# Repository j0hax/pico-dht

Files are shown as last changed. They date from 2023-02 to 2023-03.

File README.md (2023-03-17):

# pico-dht
Digital temperature and humidity reporting for the Raspberry Pi Pico, used to continuously monitor a server room at the Mechanical Engineering Campus of Leibniz University Hannover.

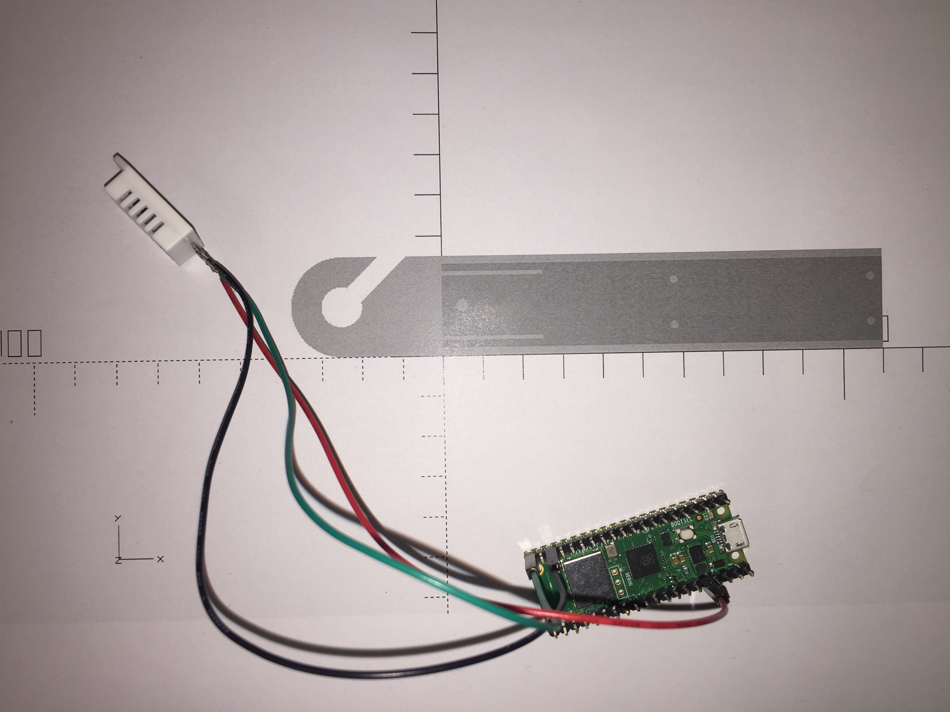
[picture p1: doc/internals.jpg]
The project without its case


## Hardware Used
1. Raspberry Pi Pico
2. DHT22/AM2302 or DHT11 sensor
3. Wires/Breadboard
4. 3D-printed case (optional)

### Wiring
| Pi Pico Label | Purpose | DHT22 Pin |
|---|---|---|
| 3V3 | Power | 1 |
| GPIO 15 | Data | 2 |
| GND | Ground  | 4 |

### Notes
- Many variants of the DHT22/DHT11 will have four pins. The third pin is unused.
- A pull-up resistor can be used but is not required, as the DHT22 has its own built-in.

## Install
By copying `main.py` to the Pico's on-board flash memory, it is executed at every boot.

Standard DHT drivers were [migrated](https://github.com/micropython/micropython/pull/9220) to `micropython-lib` starting with MicroPython 1.19, so most tutorials on the internet regarding this sensor no longer work!

The [dht](https://github.com/micropython/micropython-lib/blob/master/micropython/drivers/sensor/dht/dht.py) package can be copied over serial or installed OTA by modifying and executing `setup.py` on an internet-connected Pi Pico W. The library is should be saved to internal flash at `/lib`.

## Usage
A periodic timer is set to request sensor data every 3 seconds. The values are JSON encoded and printed over serial.[^1] The onboard LED will be on for the duration of this subroutine.

On most Linux hosts, the Pi Pico will be available under `/dev/ttyACM0`. The reading processes may need to part of the `dialout` group.

For an example implementation to read this data, see [dht22-nagios](https://github.com/j0hax/dht22-nagios).

### Connection Errors
If the wires are not soldered and knocked around, a connection may become flaky and a GPIO error can occur. Any errors when reading data are reported in the JSON's `error` attribute as a POSIX errno.

## Case
The 3D-Printed case can be used to mount the internals. It features a hook to hang the arrangement from the ceiling.

[OpenSCAD](https://openscad.org/) is used to model, customize and compile the final STL.

[^1]: Unfortunately, WPA2-EAP Networks such as eduroam are not supported very well by MicroPython at the moment.

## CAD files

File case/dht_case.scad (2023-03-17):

$fn=128;

// Sensor dimensions
/*
    swidth = 15 + 1;
    sheight = 25 + 1;
*/

swidth = 12 + 1;
sheight = 15.5 + 1;
sdepth = 5.5 + 1;

// Pi dimensions
pwidth = 21 + 2;
pheight = 51 + 2;

module hook(d=15, w=30, h=32) {
    difference() {
        hull() {
            //translate([0, 0, 10])
            cylinder(h=h/2, d=w);
            translate([w/2 - 1, -w/2, 0])
            cube([1, w, h]);
        }
        
        // Inner cylinder and slit
        cylinder(h=h, d=d);
        
        rotate([0, 0, 67.5])
        translate([0, -2.55, 0])
        cube([w, d/2, 30]);
    }
}

module sensorbody(l=100, w=30, h=30) {
    // Sensor offsets
    sxo = 2;
    syo = (w-swidth)/2;
    szo = h - sdepth;
    
    pxo = (l-pheight) - 2;
    pyo = (w-pwidth)/2;

    
    difference() {
        // Body
        cube([l, w, h]);
        
        // Sensor section
        translate([sxo, syo, szo])
        cube([sheight, swidth, sdepth]);
        
        // Cable channel
        mid = (w - 10) / 2;
        translate([sxo + sheight, mid, 2])
        cube([l, 10, h]);
        
        // Screw holes
        translate([l/3, 0, 0]) {
            translate([0, 5, 0])
            cylinder(h=h, d=3);
            
            
            translate([0, w-5, 0])
            cylinder(h=h, d=3);
        }
        
        // Pi section
        translate([pxo, pyo, 2])
        cube([pheight, pwidth, h]);
        
        // IKM Logo in the Pi Part
        translate([pheight, w, h/4])
        rotate([90, 0, 0])
        linear_extrude(w)
        import("ikm-logo.svg");
    }
    
    // Pin -- not needed for DHT11
    /*
        translate([sxo + (5.1 / 1.5), syo + swidth/2, szo])
        cylinder(d=2.9, h=(h-szo)/2);
    */
}

translate([-15, 15, 0])
hook();
sensorbody();

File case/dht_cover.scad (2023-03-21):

$fn=128;

// Sensor dimensions
swidth = 12 * 0.9;
sheight = 15.5 * 0.9;

// Pi dimensions
pwidth = 21 + 2;
pheight = 51 + 2;

module cover(l=100, w=30, h=2) {
    difference() {
        cube([l, w, h]);
        
        // Sensor Hole
        syo = (w-swidth)/2;
        sxo = 2;
        translate([sxo, syo, 0])
        cube([sheight, swidth, h]);
        
        // Screw Holes
        translate([l/3, 0, 0]) {
            translate([0, 5, 0])
            cylinder(h=h, d=3);
            
            
            translate([0, w-5, 0])
            cylinder(h=h, d=3);
        }
    }
    
    // Bottom cover
    hull() {
       inswidth = 9;
       byo = (w - inswidth) / 2;
       translate([l - 2, byo, -22]) {
           translate([-10, 0, 22])
           cube([1, inswidth, 1]);
           cube([2, inswidth, 22]);
       }
    }
}

cover();

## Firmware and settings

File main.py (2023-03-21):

import json
import errno
import _thread
from utime import sleep
from lib.dht import DHT11
from machine import Pin, ADC

sleep(1)

# Address the onboard LED
led = Pin("LED", Pin.OUT)

# Address the DHT22 Module
sensor = DHT11(Pin(15, Pin.IN, Pin.PULL_UP))

# Address the onboard temperature diode
sensor_diode = ADC(4)

# Reference voltage divided by ADC resolution
conversion_factor = 3.3 / (1 << 16)

# Synchronization control
baton = _thread.allocate_lock()

# Our Data dict
data = dict()

def measure_onboard() -> float:
    """Measures temperature using a diode on the RP2040.
    The calculated temperature may fluctuate with the reference voltage.
    For more information see section 4.9.5 of the RP2040 documentation.
    """
    voltage = sensor_diode.read_u16() * conversion_factor
    c = 27 - (voltage - 0.706) / 0.001721
    return round(c)


def measure() -> dict:
    """Measures DHT and onboard temperature values.
    In case of any I/O errors, the errno field will be set.
    """
    led.on()
    t = 0
    h = 0
    o = 0
    err = 0

    try:
        sensor.measure()
        t = sensor.temperature()
        h = sensor.humidity()
        o = measure_onboard()
    except OSError as exc:
        err = exc.errno

    return {"temperature": t, "onboard": o, "humidity": h, "error": err}


def report():
    """Designed to run on the RP2040s second core.
    Its job is to update the data dict at a periodic rate.
    While measuring, the onboard LED will be turned on.
    """
    global data
    while True:
        led.on()
        baton.acquire()
        data = measure()
        baton.release()
        led.off()
        sleep(1)


# Sleep to ensure no race conditions, then start
sleep(1)
_thread.start_new_thread(report, ())

sleep(1)
while True:
    sleep(0.1)
    baton.acquire()
    print(json.dumps(data))
    baton.release()

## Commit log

2023-02-16 Speicify pin parameters
2023-02-16 Blink LED when actively measuring
2023-02-22 Read onboard temperature sensor
2023-03-07 Include case files
    [dht_case.scad, dht_cover.scad]
2023-03-07 Strengthen case walls and refactor
    [dht_case.scad]
2023-03-17 Put IKM Logo in sides
    [dht_case.scad]
2023-03-17 Ignore 3D Printing files
2023-03-17 Reduce hook size
    [dht_case.scad]
2023-03-17 Modify for DHT11 support
    [dht_case.scad, dht_cover.scad]
2023-03-21 Improve cover durability
    [dht_cover.scad]
